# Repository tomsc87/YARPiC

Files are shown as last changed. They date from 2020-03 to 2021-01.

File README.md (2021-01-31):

[UPDATE: 31/01/2021]

Goddammit! Another update for January 2021. While playing around, trying to make a double fan top for one of my Pis, I noticed that I borked the dc_text intersection in the last update, meaning the grill went through the dc_text (and made rendering dc_text so much slower).

Here are the changes:

<ul>
<li>Fixed dc_text fan intersection.</li>
<li>Removed leftover code used for internal testing.</li>
</ul>

This really is the last update of January 2021... mainly because I probably won't notice any other bugs until tomorrow.

[UPDATE: 30/01/2021]

Okay, I lied. This really will be the final update of January 2021 (and for a while).

<ul>
<li>Added the option for double fans (some restrictions apply), which was suggested by Thingiverse user <a href="https://www.thingiverse.com/muga/" target="_blank">Muga</a>.</li>
<li>Changed the camera cutout slightly (you can't have it when you have double fans).</li>
</ul>

That's it. No more updates until my big overhaul.

[UPDATE: 28/01/2021]

This should be the final update of January 2021 (and for a while).

Here's what's changed:

<ul>
<li>Moved all hinge parts into modules.</li>
<li>Created a test part for hinge so you can dial in horizontal expansion settings without having to print out a whole case.</li>
<li>Refined hinge slightly.</li>
<li>Added cutout for camera ribbon cable. (Suggested by Thingiverse user <a href="https://www.thingiverse.com/gregkster/designs" target="_blank">Gregkster</a>.)</li>
<li>Updated .json file.</li>
</ul>

Future updates will come few and far between. I have some ideas; however, they'll take some time and will likely require a complete redesign.

[UPDATE: 25/01/2021]

Today, I bring you the long-awaited hinged cover for the microSD card slot. It's still experimental, and you may need to adjust your horizontal expansion settings in your slicer software. It is rather slap-dash at the moment, so it increases render times by between 20 and 25% compared with the "Open" option, but I will refine it over time.

Here are all the changes:

<ul>
<li>Changed sd_card options to include the hinged cover. ("Yes" is now "Open", "No" is now "Closed", and added "Cover (experimental)" for the hinged cover.)</li>
<li>Updated the .json file.</li>
<li>Minor bug fixes.</li>
</ul>

In the next update, I hope to refine the microSD card cover enough so you can print out a test of it without having to waste time and material by printing out a full case to get your horizontal expansion settings dialled in. I might also add an option for a camera ribbon cable cutout in the top of the case as well as camera mounting options; however, they're low on my priorities list right now.

[UPDATE: 21/01/2021]

Just a small update, with no new features, but tidied up the code.

Here are the changes:

<ul>
<li>Ports for different models merged together. (Using mostly inline conditionals, but some nested conditionals where needed.)</li>
<li>Moved front and side ports into separate modules. (So you don't have to render ports twice when new_io is set to "yes".)</li>
<li>Using inline conditional for building the main body of bottom() instead of nested conditional. (Had already done this for top(), but never got round to doing it for bottom().)</li>
</ul>

In all, 109 lines of code have been removed in this update.

Still working on a hinged cover for the microSD card. Might commit that to a new branch tomorrow.

[UPDATE: 13/01/2021]

It's been a crazy 9 months. Happy new year. Hope you're all doing well. Most of my time was spent doing nothing with YARPiC; however, over the last 2 months, YARPiC has gone through quite a few revisions that I've been too busy to finalize and upload (or "commit" as I think I recall it being known as on the GitHubs).

Anyway, here are the changes:

<ul>
<li>Option of a deeper side cutout to give better clearance to HDMI (because the Pi has to go in sideways with this option, I've added a cutout at the back when sd_card option is set to "no" to give clearance; if sd_card option is set to "yes", you can just insert the microSD card after installing the board) (only tested on Pi4B with corners option set to "yes"; might be some clearance problems with Pi3A and Pi3B with corners option set to "no" (I've tried to mitigate it, but, again, I haven't tested it)).</li>
<li>Tapered board screw holes when corners option set to "yes" to better guide screws.</li>
<li>(Almost) complete freedom to manipulate text; text can be moved anywhere and rotated any amount (in 0.5 degree increments); spacing between two lines of text can be increased or decreased; text can even be printed in the fan grill, but it won't cover the screw holes.</li>
<li>Added option for rail mounting from rear (SD card side) of the case for better clearance when mounting to Prusa i3 printers.</li>
<li>Option for cooling slots along the GPIO side of the case, as well as both the SD card side and GPIO side (untested).</li>
</ul>

I think that's everything that's been changed. Might have moved the USB and ethernet slightly, but nothing major. Oh, and I finally got round to sorting out the indents (that was a pain in the arse).

In the next update, I'll probably just tidy up the ports, which should get rid of between 50 and 70 lines of code. I was also working on a hinged cover for the microSD card; however, it was getting a bit too demanding, so I put that on hold; maybe that will be in the next update as well.

[UPDATE: 21/04/2020]

Small update. Here's the changes:

<ul>
<li>Removed the restriction for rail and corners together.</li>
<li>Added embedded screw hole to the rail.</li>
<li>Added new corner/rail combination to examples.</li>
<li>Changed the lip on the top of case so it no longer uses the Minkowski function (cuts about 2 seconds off the render time).</li>
</ul>

[UPDATE: 12/04/2020]

All the customizability you've come to expect from YARPiC, but now in a smaller form factor. Here's what's new:

<ul>
<li>Added support for the Raspberry Pi 1 Model A+ and 3 Model A+.</li>
<li>Lots of translates to make A+ work smoothly.</li>
<li>Added option to fully embed screws on fans and/or corners.</li>
<li>Removed most unused code.</li>
<li>Tidied up code (especially most of the misplaced indents caused by commenting out sections of code).</li>
</ul>

As always, feedback would be much appreciated.

[UPDATE: 30/03/2020]

Minor update.

<ul>
<li>Merged part translates from "touchscreen" branch because they're cleaner.</li>
<li>Merged GPIO/fan translate from mkgin's fork because it helps remove redundant code.</li>
</ul>
</ul>

[UPDATE: 12/03/2020]

Another small update.

<ul>
<li>Redesigned nut trap for corners.</li>
<li>Fixed corner impinging on front cutout for Pi4.</li>
</ul>

[UPDATE: 09/03/2020]

Just a small update. I've tweaked the edge_detection function for "dc_text" and made it default. It doubles render times for dc_text (when set to bevelled), but that comes out at 6 seconds (much better than the 38 seconds in the last update). Unfortunately, when bevel is set to "no", it comes out at 16 seconds for reasons that I don't fully understand because it's completely illogical (it's still better than 38 seconds). As a result, if your text doesn't extend beyond the edge of the case, I recommend rendering dc_text with bevel set to "yes", even if you don't have bevel enabled on the case.

[UPDATE: 08/03/2020]

Lots of changes in this update.

<ul>
<li>Bevelled side cutout (power, HDMI, audio) to make printing easier.</li>
<li>Larger micro HDMI cutouts for Pi 4.</li>
<li>Option to remove access to SD card (suggested by @<a href="https://www.thingiverse.com/mikegi/about" target="_blank">mikegi</a>).</li>
<li>Moved corner nut housing up a bit (M3*16 bolts can be used instead of M3*20), made slightly wider (so nuts fit in better), and added a hexagon (so it holds nuts in place better).</li>
<li>Added supports for corner nut housing roof (can easily be removed in post processing with side cutters or a craft knife).</li>
<li>Added a full layer above corner nut housing as support for screw hole (can easily be removed in post processing with a drill, file, or even just a screw if you're lazy (like me)). (Can be adjusted for different layer heights.)</li>
<li>New embedded screw holes on top of case with corners set to "yes". (I.e. no more need for supports.)</li>
<li>screw_hole variable now sets the screw hole size for the stand offs when corners is set to "yes". (Was overlooked before because I never print with corners any more.)</li>
<li>Dual colour text edge detection. Now the text can extend beyond the edge of the case and dc_text will conform to it. (<strike>Must be set manually because it drastically increases render times.</strike>)</li>
<li>Minor code refinements to help reduce render times.</li>
</ul>

I think that's all the changes in this update.

Again, Thingiverse isn't giving out the correct file in the main download, so go to Thing Files and download YARPiC_March_2020.zip to get the most recent version.

[ORIGINAL]

I couldn't find a Raspberry Pi case that I liked or that met my needs, so I made one myself.

My basic requirements were:
<ul>
<li>Could house an Asus Tinker Board with stock heatsink</li>
<li>Could house a 40*40*10 fan as well</li>
<li>Used nuts and bolts (since clip together cases always break)</li>
<li>Not too thin and flexible (too many cases on here have, like, 0.5mm thick surfaces, which is just too flexible)</li>
<li>Could fit my chunky Amazon Basic USBs</li>
<li>Didn't look like it was trying to be a retro console (the most important thing)</li>
</ul>

After a couple of hours in OpenSCAD and a few prototypes later, I give you YARPiC.

To properly use it, you will need:
<ul>
<li> 4 x M3*16 bolts (for the fan)</li>
<li> 4 x M3*20 bolts (for the lid)</li>
<li> 8 x M3 nuts (for the fan and lid)</li>
<li> 4 x M2.5*5 screws (for the board)</li>
<li> 1 x Raspberry Pi (1 B+, 2 B, 3 B, 3 B+) or Tinker Board (or any SBC with the same form factor)</li>
<li> 1 x 40*40*10mm fan (ideally 5V; I went for the Noctua one)</li>
</ul>

Tree supports in Cura are awesome, but they're not perfect, so you might need to tidy up the nut housing; I used a craft knife, small circular file, and a pair of tweezers to get it looking nice.

[UPDATE: 15/03/2019]

I've included a customizable OpenSCAD file, so you can customize YARPiC to your needs.

What you can now do:
<ul>
<li>Change fan size.</li>
<li>Add slot for GPIO.</li>
<li>Bevel the edges.</li>
<li>Add exhaust slots.</li>
<li>Add embedded text.</li>
<li>Add dual colour text.</li>
<li>Change wall size.</li>
<li>Render bottom, top, and text separately.</li>
</ul>

If you have any questions, complaints, or suggestions, feel free to leave a comment.

[UPDATE: 19/03/2019]

I wanted to mount this case to my printer because I wasn't happy with the case I had. As a result, I had to find a way to add a V-slot rail to it, which meant I had to get rid of the corner screws and find another way to fix the lid in place. Thus, I give you "YARPiC No Corners". This is the intermediary stage (without the V-slot rail), and a preview of things to come.

What you'll need:
<ul>
<li>4 x M3*16 bolts (for the fan)</li>
<li>4 x M3 nuts (for the fan)</li>
<li>4 x M2.5*8 screws</li>
<li>Raspberry Pi</li>
<li>40*40*10mm 5V fan</li>
</ul>

Again, you will need to slice with supports (ideally tree supports in Cura) so that the embedded screw holes don't collapse when printing.

In the coming days, I will add the alterations to the customizer so you can add text, change fan size, add V-slot rail etc.

[UPDATE: 23/03/2019]

As promised, here's the updated version of the YARPiC customizer so you can make YARPiC without the corner screw holes.

Here's what's new:
<ul>
<li>Option to remove the corner screw holes and add through-board screws for the top.</li>
<li>Add V-slot mounting rail for 3D printers that use 2020, 2040, 4040 extrusion. (NOTE: V-slot cannot be used with corners.)</li>
<li>Up to two lines of text.</li>
</ul>

Bug fixes:
<ul>
<li>Fixed bevelled edge with GPIO set to "yes".</li>
</ul>

As always, I hope you enjoy, and look forward to seeing your creations. If you have any questions, suggestions, or complaints, leave a comment. 
[UPDATE: 04/04/2019]

Did someone say "VESA mounts"? Okay, no one said "VESA mounts", but I decided to add them anyway.

Updates:
<ul>
<li>VESA mounts.</li>
</ul>

As always, if you have any complaints, comments, or suggestions, leave them in the comments.

[UPDATE: 02/04/2019]

Bug fix:
<ul>
<li>Increased the size of screw holes from 2.6mm to 3mm to reduce stress on (and subsequent breakage of) the top when "corners" is set to "No".</li>
<li>Fixed screw towers going through text on lid.</li>
</ul>

[UPDATE: 25/06/2019]

Added support for the new Raspberry Pi 4 Model B. This is untested. While I do have my Pi 4, all my printers are out of action at the moment. As a result, feedback would be greatly appreciated.

[UPDATE: 22/08/2019]

My main printer is working again, so I've been able to work on this again.

Change log:
<ul>
<li>Modified fan grill to decrease render time (by up to ~43%) and increase airflow (~6.5% better cooling)</li>
<li>Smaller power port when Pi4 is set to "No"</li>
<li>Deeper screw holes on the bottom </li>
<li>Modified top mounts to make them stronger</li>
<li>Added screw hole test</li>
</ul>

Things I still have to do:
<ul>
<li><strike>Rewrite the entirety of the top of the case because the code is a mess and drastically increases render times.</strike></li>
</ul>

[UPDATE: 25/08/2019]

I notices there was a problem with the standoffs breaking (caused by the deeper screw holes bug fix in the last update), so this is a quick bug fix for that.

Changes:
<ul>
<li>Changed diameter of standoffs from 6mm to 8mm to stop breakage. (Untested, but should work)</li>
</ul>

[UPDATE: 06/09/2019]

Right, I've done a massive overhaul. Here are the changes:

<ul>
<li>Removed the reliance on the third-party bevel library for the bevelled edge option</li>
<li>Fewer, larger cooling slots on the back to increase airflow slightly</li>
<li>Embedded screw holes that no longer need supports</li>
<li>Added cutout for easier insertion and removal of Pi4</li>
</ul>

I think that's all the changes. As always, feedback would be much appreciated.

[UPDATE: 18/09/2019]

I finally installed OpenSCAD 2019.05 and discovered the amazing Customizer in there, so I've made yarpic_customizer.scad compatible with that. I think it makes my code more of a mess, but it makes it easier to use with the built-in Customizer. And, with it, I've included a .json file with some pre-configured YARPiCs (including the one I use to test render times).

Speaking of render times, I've also tidied up the code in the maths/yarpic_model.scad file (removing redundant code that got added over time), resulting in ~38% faster render times (compared with the first Raspberry Pi 4 revision).

Also, I noticed a bug where the fan mesh stuck out the side of the case when "gpio" and "fan" were set to "yes", so I made the mesh smaller. Because of this, I didn't include an option for 50mm fan in the Customizer (although, you can add it manually), so the smaller mesh shouldn't be a problem (not that you can fit a 50mm fan in the case with "gpio" set to "yes" anyway (I'm not even sure a 50mm fan will fit in the case without "gpio" set to "yes" because I haven't tried it)).

Finally, I've made it so you cannot render the "screwtest" or "dc_text" with the case itself. Obviously, rendering "dc_text" with the case would defeat the purpose of having text (because it would fill in the text in the .stl). And the "screwtest" only takes 15 minutes to print and should be printed (and the "screw_hole" variable set correctly) before you print the case anyway.

Well, I think that's all the changes in this (hopefully final) revision.

If you notice any bugs, let me know in the comments section.

[UPDATE: 13/02/2020]

Just a small update with two changes:

<ul>
<li>Changed the V/T-slot. It now requires two M3 T-nuts and two M3x8 bolts. This makes it a lot stronger.</li>
<li>Reduced the default fragment number ($fn) from 50 to 24. It doesn't reduce detail too much, but halves the render time, so it's a worthy trade off. Of course, you can still set it whatever you like in the customizer.</li>
</ul>

Thingiverse is still giving out the 18th September 2019 update when you click "download all files", so, for the time being, go over to the "thing files" tab and download the "yarpic_customizer_2020.zip" file from there.

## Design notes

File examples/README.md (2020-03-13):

<h1><u>YARPiC Examples</u></h1>

Feel free to upload your customized YARPiC .stl files, and leave a little note about what you're using YARPiC for (e.g. Pi-Hole, daily driver, home automation, etc).

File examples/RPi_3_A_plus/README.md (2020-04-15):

<h1><u>Raspberry Pi 3 Model A +</u></h1>

I had the random urge to add support for the 1 A+ and 3 A+ models.

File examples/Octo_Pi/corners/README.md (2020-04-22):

<h1><u>OctoPi</u></h1>

With the new rail design, I figured I could allow corners and rail together. This was the test print of that, and it works well.

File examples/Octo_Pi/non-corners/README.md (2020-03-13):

<h1><u>OctoPi</u></h1>

To communicate with my printers, I use OctoPi (OctoPrint) on a Raspberry Pi 3 Model B. This is attached to my main printer (Geeetech A10M) with this YARPiC. It's the reason I got rid of corners for a while (see the main README.md for the full story behind that)..

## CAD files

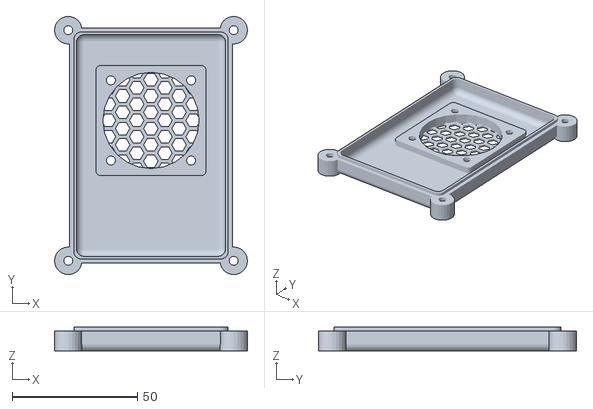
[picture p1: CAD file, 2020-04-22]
examples/Octo_Pi/corners/OctoPi_corners_top.stl
77.0 x 103.0 x 9.47

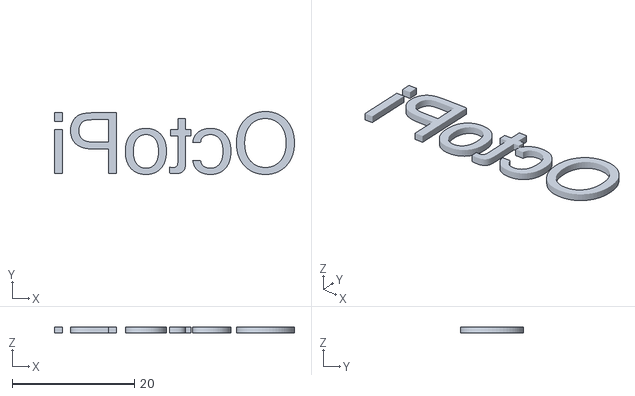
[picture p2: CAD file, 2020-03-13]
examples/Octo_Pi/non-corners/OctoPi_text.stl
39.3 x 10.3 x 1.00

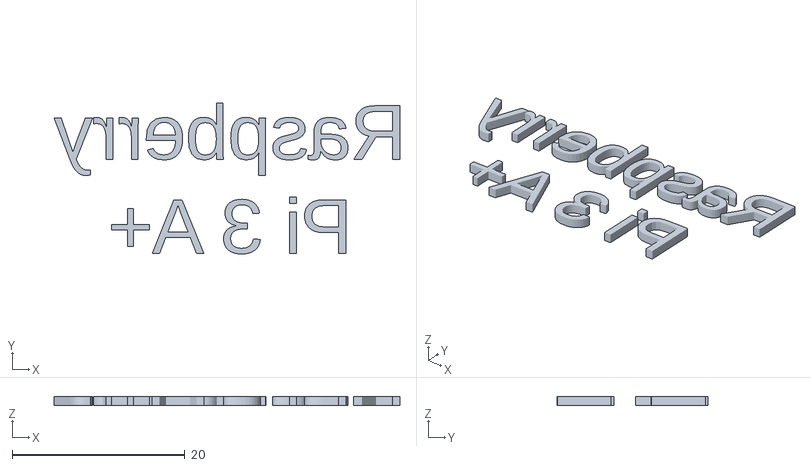
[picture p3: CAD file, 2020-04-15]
examples/RPi_3_A_plus/yarpic_text.stl
40.0 x 17.5 x 0.999

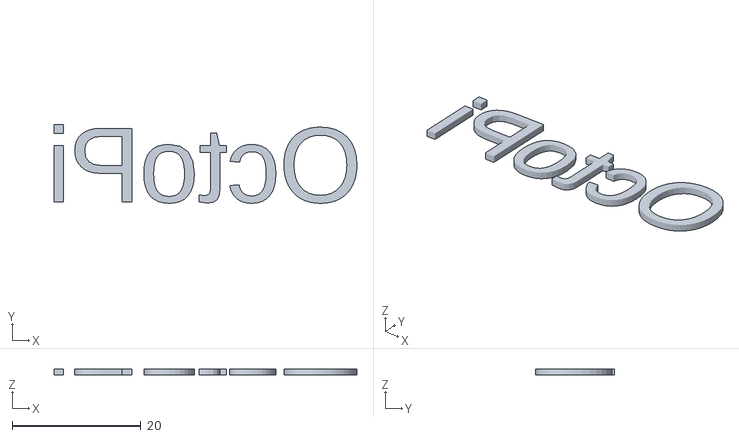
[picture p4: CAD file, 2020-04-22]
examples/Octo_Pi/corners/OctoPi_corners_top_text.stl
47.0 x 12.2 x 0.999

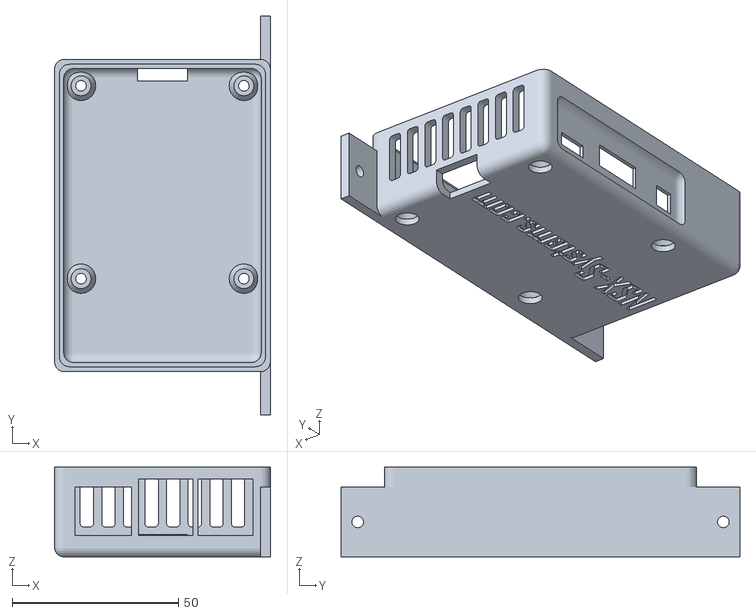
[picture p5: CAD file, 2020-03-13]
examples/Octo_Pi/non-corners/OctoPi_bottom.stl
65.0 x 120.0 x 27.0

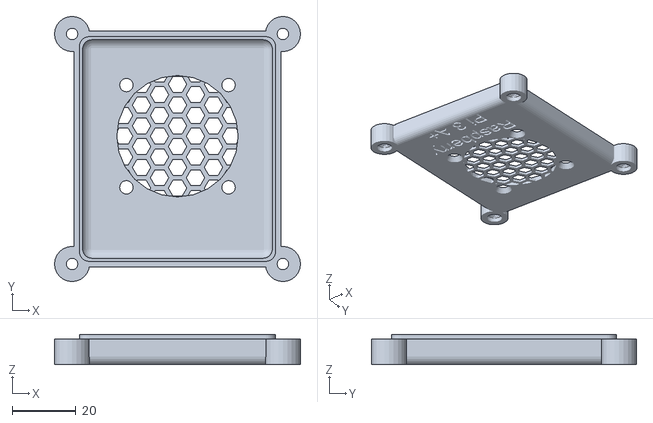
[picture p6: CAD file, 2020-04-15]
examples/RPi_3_A_plus/yarpic_top.stl
77.0 x 83.0 x 9.47

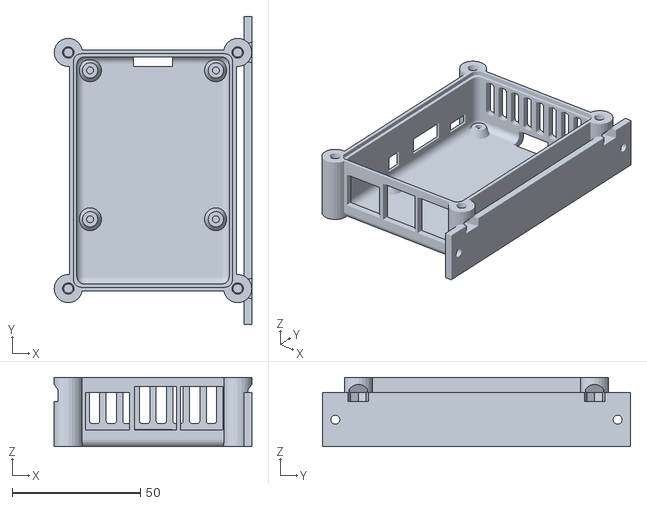
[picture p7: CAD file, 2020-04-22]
examples/Octo_Pi/corners/OctoPi_corners_bottom.stl
77.0 x 120.0 x 27.0

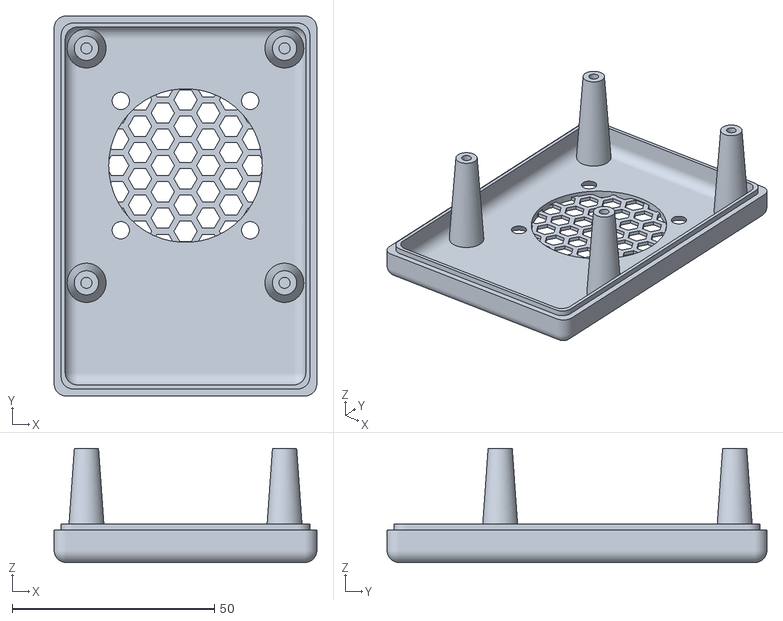
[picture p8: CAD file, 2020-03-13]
examples/Octo_Pi/non-corners/OctoPi_top.stl
65.0 x 94.0 x 28.2

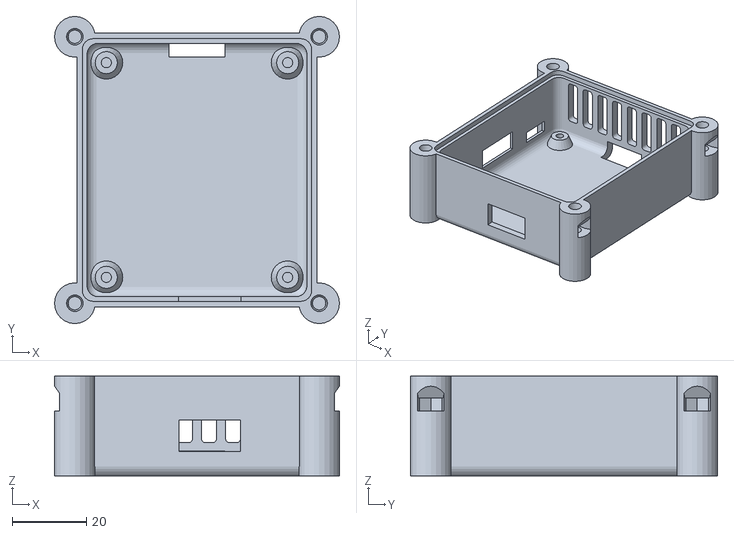
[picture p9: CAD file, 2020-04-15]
examples/RPi_3_A_plus/yarpic_bottom.stl
77.0 x 83.0 x 27.0

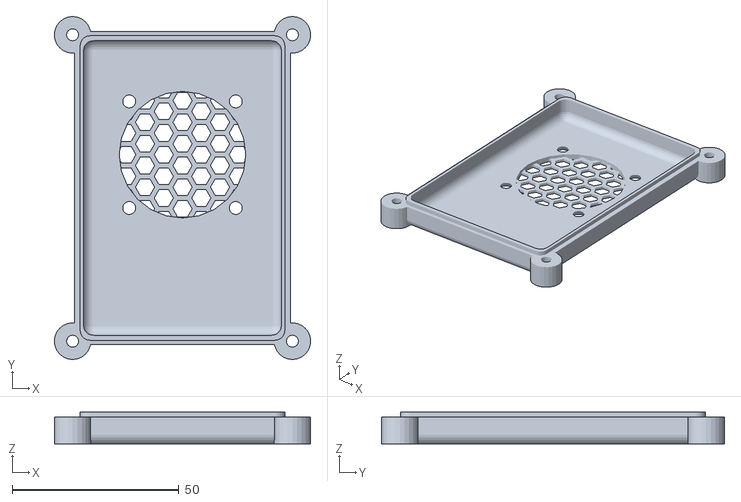
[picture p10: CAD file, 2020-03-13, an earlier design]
examples/Tinker_test/yarpic_top.stl
77.0 x 103.0 x 9.47

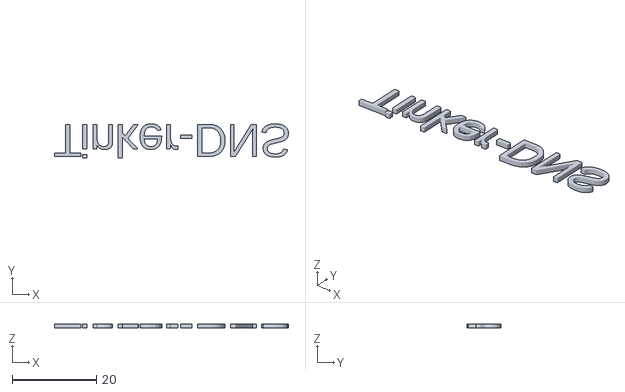
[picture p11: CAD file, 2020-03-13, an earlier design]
examples/Tinker_test/yarpic_text.stl
55.7 x 8.19 x 0.999

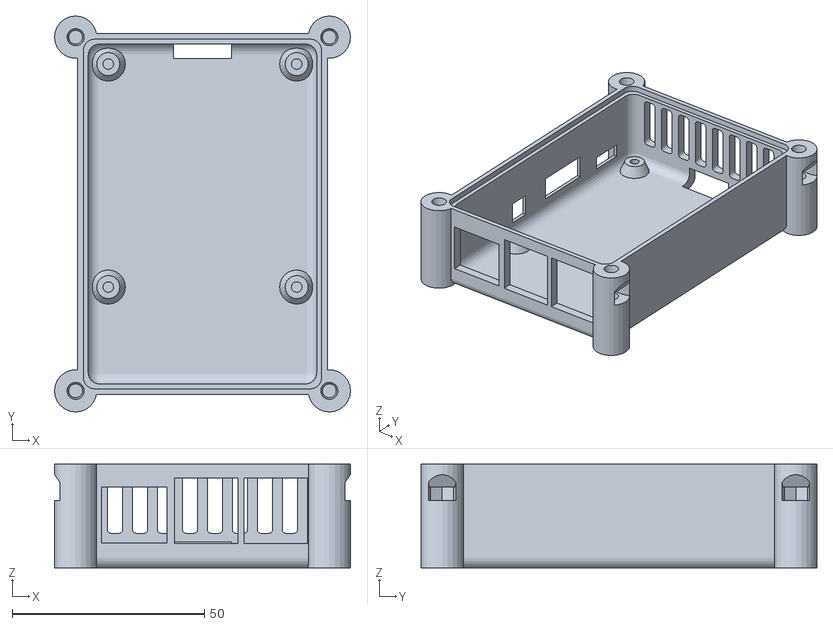
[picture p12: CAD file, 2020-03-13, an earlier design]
examples/Tinker_test/yarpic_bottom.stl
77.0 x 103.0 x 27.0

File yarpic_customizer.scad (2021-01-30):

// Hello, you lovely people. I added some more features to my Yet Another Raspberry Pi Case (YARPiC), and decided to release a customizable source code for you.

// To make it as simple as possible, I've split it into two parts: 1) a customizer (this document), and 2) another file that does all the hard work (maths/yarpic_model.scad). If I've done my job correctly, you shouldn't need to touch the latter (and see how much of a mess my coding is).

// Anyway, I hope you find this easy to use and post your makes to Thingiverse. If you have any comments, complaints, or suggestions, feel free to leave a comment (here: https://www.thingiverse.com/thing:3464513, or here: http://github.com/tomsc87/YARPiC).

include <maths/yarpic_model.scad>

/*[Main]*/

// Moves the ports around for different models.
model="pi3b"; //[pi3b:Raspberry Pi 1 B+/2 B/3 B/3 B+/Tinker Board,pi4:Raspberry Pi 4 B,pi3a:Raspberry Pi 1A+/3A+]

// Render both top and bottom, or just top or bottom.
part="both"; // [both:Both,bottom:Bottom,top:Top]

// For bevelled top and bottom edges. This seriously reduces performance, so change this last if you want bevelled edges.
bevel="no"; //[no:No,yes:Yes]

// This re-adds the corners from my original design and removes the through-board screw holes to hold the top in place. This cannot be used with the V-slot mounting rail.
corners="no"; //[no:No,yes:Yes]

// If using corners, set the layer height you plan to print at so a single layer gets printed above the nut housing as a base for the screw holes. You can use a drill or small circular file to remove it in post processing. If not using corners, this doesn't need to be set.
layer_height=0.2;

// Increase to add smoothness (slow render); decrease to reduce smoothness (fast render). Default is "24".
$fn=24;

/*[Bottom]*/

// Add cooling slots on the rear (microSD side) wall.
cooling_slots="no"; //[no:None,back:Back,side:Side,both:Both]

// Adds a 75*75 and 100*100 VESA mount to the bottom of the case. The 100*100 works with corners, but the 75*75 might be a bit close (I haven't actually tested it yet). Also, cannot be used with rail.
vesa="no"; //[no:No,yes:Yes]

// Adds mounting holes for 2020 aluminium (aluminum) extrusion V-slot so you can mount the case to a 3D printer that uses V-slots such as the Creality Ender 3, Geeetech A10(M)/A20(M)/A30(M), or Original Prusa i3 MK3(S).
rail="no"; //[no:None,side:Side,back:Back]

// Thingiverse user mikegi wanted the option to have the SD card covered, so here it is.
sd_card="open"; //[open:Open,closed:Closed,cover:"Covered (experimental)"]

// Moves the side I/O cutout in for better HDMI clearance. Also adds spacing at back if you have sd_card set to "closed".
new_io="no"; //[no:No,yes:Yes]

/*[Top]*/

// Adds access to GPIO header through lid. This will also offset the fan slightly (if fan is enabled).
gpio="no"; //[no:No,yes:Yes]

// Adds fan hole (or two) on lid. The Double option doesn't work on 40mm fans (yet) or fans larger than 25mm with the "Raspberry Pi 1A+/3A+" model option, and will just default to Single.
fan="no"; //[no:No,single:Single,double:Double]

// Change fan size. It should work for any size fan (assuming it fits in the case); however, I've only tried it with the sizes that are listed. Input should be in millimetres between "25" and "40".
fan_size=40; //[25,30,40]

// This option allows you to fully embed the fan and/or corner screws for a cleaner look. (Might not work with 25mm fans.)
full_embed="no"; //[yes:Yes,no:No]
// Thingiverse user Gregkster suggested a cutout for a camera ribbon cable, so that's what I've done. Unfortunately, I have no camera mounting options, yet; however, I might do that in a future update.
camera="no"; //[yes:Yes,no:No]

/*[Text options]*/

// Add text. Pretty obvious, right?
add_text="no"; //[no:No,yes:Yes]

// Whatever you put in the quotation marks will appear on the top of the case.
line1="YourTextHere1";

// Same as above. However, you can leave this blank for just a single line.
line2="YourTextHere2"; 

// Check "Help > Font List" to see all available fonts (try "Chiller"; it's my favourite). (I might add a dropdown font list in future revisions.)
font="";

// This is pretty obvious.
text_size=6.5; //[5:0.5:13]

// Rotate text allows you to have more than just 0 and 180 degrees on the text.
rotate_=0; // [-180:0.5:180]

// This moves the text up (positive) and down (negative). Movement is absolute (i.e. relative to the case, not the text itself), so rotation will have no impact on the location. Another thing to note is that the text can go through the fan grill, but not the fan holes.
move_y=0; // [-10:0.5:70]

// This moves the text left (positive) and right (negative). (Yes, the slider is inverted, but there's not a lot I can do about that.)
move_x=0; // [-10:0.5:10]

// This adjusts the spacing between the two lines of text.
spacing=0; //[-10:0.5:10]

// This adds a dual colour option for text. Obviously, you have to render this separately from everything else.
dc_text="no"; //[no:No,yes:Yes]

/*[Test]*/

// If you want to use the "Covered" option for sd_card, it's recommended that you print a sample of the hinge so you can dial in your slicer's horizontal expansion settings. It should take up to 20 minutes to print, and it's better than spending 7 hours on a print that's wasted because the cover won't open or is too loose.
hingetest="no"; //[no:No,yes:Yes]

// After changing hotend and nozzle on my printer, I was having problems with the screw holes for the top not being tight enough to grip the screws. Instead of printing out a new top every time, I made a test to get the right size.
// Print this out and then change the variable "screw_hole" if your screws are too tight (increase the variable) or too loose (decrease the variable) until the screws fit snugly.
screwtest="no"; //[no:No,yes:Yes]
screw_hole=2.45;

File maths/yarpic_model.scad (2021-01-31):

// Hello, you lovely people. I added some more features to my Yet Another Raspberry Pi Case (YARPiC), and decided to release a customizable source code for you. 

// To make it as simple as possible, I've split it into two parts: 1) a customizer (../yarpic_customizer.scad), and 2) another file that does all the hard work (this file). If I've done my job correctly, you shouldn't need to touch the latter (and see how much of a mess my coding is).

// Anyway, I hope you find this easy to use and post your makes to Thingiverse. If you have any comments, complaints, or suggestions, feel free to leave a comment (here: https://www.thingiverse.com/thing:3464513, or here: https://github.com/tomsc87/YARPiC ).

// DON'T TOUCH!! Important maths stuff. DON'T TOUCH!!

if((rail=="side"||rail=="back")&&(vesa=="yes")){
    translate([0,sd_card=="cover" ? 10:0,0]) linear_extrude(2) text("Turn off either rail or vesa.", halign="center", valign="center");
}
else{}

if(rail=="back"&&sd_card=="cover"){
	translate([0,vesa=="yes" ? -10:0,0]) linear_extrude(2) text("Turn off either back rail or SD cover.", halign="center", valign="center");
}
else{}

if(part=="bottom"){
	if((rail!="no"&&vesa=="yes")||(dc_text=="yes")||(screwtest=="yes")||(hingetest=="yes")||(rail=="back"&&sd_card=="cover")){}
    else{
        translate([0,model=="pi3a" ? -10:0,0]) bottom();
    }
}
else {}

if(part=="top"){
    if((rail=="side"||rail=="back")&&vesa=="yes"||(dc_text=="yes")||(screwtest=="yes")||(hingetest=="yes")){}
    else{
        translate([0,model=="pi3a" ? -10:0,0]) top();
    }
}
else {}

if(part=="both"){
    if((rail=="side"||rail=="back")&&vesa=="yes"||(dc_text=="yes")||(screwtest=="yes")||(hingetest=="yes")||(rail=="back"&&sd_card=="cover")){}
    else{
        translate([-50,model=="pi3a" ? -10:0,0]) top();
        translate([50,model=="pi3a" ? -10:0,0]) bottom();
        if(vesa=="yes"){
			translate([50,model=="pi3a"&&corners=="yes" ? -10:0,0]) vesa();
        }
        else{}
    }
}
else{}

if(dc_text=="yes"){
    if(screwtest=="yes"||hingetest=="yes"){}
    else{
        if(part=="both"){
            translate([-50,model=="pi3a" ? -10:0,0]) dc_text();
        }
        else if(part=="top"){
            translate([0,model=="pi3a" ? -10:0,0]) dc_text();
        }
        else{}
    }
}
else {}

if((vesa=="yes")&&(part=="bottom")){
    if((rail=="side"||rail=="back")&&(corners=="yes"||vesa=="yes")||(dc_text=="yes")||(screwtest=="yes")||(hingetest=="yes")){}
    else{
        translate([0,model=="pi3a"&&corners=="yes" ? -10:0,0]) vesa();
    }
}
else {}

if(screwtest=="yes"){
	if(hingetest!="yes"){
		screwtest();
	}
	else{}
}
else {}

if(hingetest=="yes"){
	if(screwtest!="yes"){
		hinge();
	}
	else{}
}
else{}

if(screwtest=="yes"&&hingetest=="yes"){
	translate([0,0,0]) linear_extrude(2) text("Turn off either screwtest or hingetest.", halign="center", valign="center");
	}
else{}

module bottom(){
    difference(){
        union(){
            difference(){
                union(){
                    difference(){
                        union(){
                            // Case
                            if(bevel=="yes"){
                                translate([0,model=="pi3a" ? 10:0,2.975]){
                                    minkowski(){
                                        linear_extrude(27)  square([59,model=="pi3a" ? 68:88], center=true);
                                        sphere(3);
                                    }
                                }
                            }
                            else{
                                translate([0,model=="pi3a" ? 10:0,0]) linear_extrude(27) offset(3) offset(-3) square([65,model=="pi3a" ? 74:94], center=true);
                            }
                            // V-slot
                            if(rail=="side"){
                                difference(){
                                    union(){
                                        translate([corners=="yes" ? 37:31,model=="pi3a" ? 10:0,0]) linear_extrude(21) square([3,model=="pi3a" ? 100:120], center=true);
                                    }
                                    for (y=model=="pi3a" ? 45*[1,-1]:55*[1,-1]){
                                        translate([corners=="yes" ? 39.5:33.5,model=="pi3a" ? 10+y:y,10.5]) rotate([0,-90,0]) linear_extrude(10) circle(d=3.6);
                                        translate([corners=="yes" ? 37:31,model=="pi3a" ? 10+y:y,10.5]) rotate([0,-90,0]) linear_extrude(10) circle(d=6);
                                    }
                                }
                            }
                            else if(rail=="back"){
                                difference(){
                                    union(){
                                        translate([0,corners=="yes" ? 50:45.5,0]) linear_extrude(corners=="yes" ? 17.5:21) square([95,3], center=true);
                                    }
                                    for(X=42.5*[1,-1]){
                                        translate([X,corners=="yes" ? 52:47,10.5]) rotate([90,0,0]) linear_extrude(10) circle(d=3.6);
                                        translate([X,corners=="yes" ? 50:45.5,10.5]) rotate([90,0,0]) linear_extrude(10) circle(d=6);
                                    }
                                }
                            }
							else{}
                        }
                        // Rear holes for airflow
                        if(cooling_slots=="back"||cooling_slots=="both"){
                            rotate([90,0,0]) translate([0,14,-48]){
                                linear_extrude(6) for(X=[-22.75:6.5:22.75], Y=2.5) translate([X,Y,-1]) offset(1) offset(-1) square([4,15], center=true); // As awful as this is with the rotate, it's a LOT better than the alternative (minkowski).
                            }
                        }
                        if(cooling_slots=="side"||cooling_slots=="both"){
                            translate([29,model=="pi3a" ? 10:0,17]) rotate([0,90,0]){
                                linear_extrude(6) for(Y=model=="pi3a" ? [-22.75:6.5:22.75]:[-35.75:6.5:35.75]) translate([0,Y,0]) offset(1) offset(-1) square([15,4], center=true);
                            }
                        }
                        else{}
						if(new_io=="no"){
							side_io();
						}
						else{}
						front_io();
						translate([new_io=="yes" ? -30:-35.75,11,6]){
							minkowski(){
								linear_extrude(model=="pi4" ? 8.5:12) square([4,55], center=true);
								sphere(3);
							}
						}
                    }
                    if(corners=="yes"){
                        // Corners
                        translate([0,model=="pi3a" ? 10:0,0]) linear_extrude(27) for(X=33*[-1,1], Y=model=="pi3a" ? 36*[-1,1]:46*[-1,1]) translate([X,Y,-1])  circle(d=11);
                    }
                    else{}
                }
				if(model=="pi4"||model=="pi3a"){
					// Front cutout
					translate([model=="pi3a" ? 3.45:-0.5,model=="pi3a" ? -24:-44,6.4]) linear_extrude(20) square([model=="pi3a" ? 17:55,3], center=true);
				}
				else{}
				// Hollow out for lid
				translate([0,model=="pi3a" ? 10:0,25.25]) linear_extrude(10) offset(3) offset(-3) square([62,model=="pi3a" ? 71:91], center=true);
				if(bevel=="yes"){
					// Cut off top
					translate([0,model=="pi3a" ? 10:0,27]) linear_extrude(9) square([79,model=="pi3a" ? 98:118], center=true);
					// Hollow out
					minkowski(){
						translate([0,model=="pi3a" ? 10:0,5]) linear_extrude(30) square([53.5,model=="pi3a" ? 62.5:82.5], center=true);
						sphere(3);
					}
				}
				else{
					translate([0,model=="pi3a" ? 10:0,2]) linear_extrude(30) offset(3) offset(-3) square([59.5,model=="pi3a" ? 68.5:88.5], center=true);
				}
                if(corners=="yes"){ // I could add all this to the nut_trap() module, but it adds about 10 seconds to the render time.
                    translate([0,model=="pi3a" ? 10:0,0]){
                        for(X=33*[-1,1], Y=model=="pi3a" ? 36*[-1,1]:46*[-1,1]){
                            translate([X,Y,23.5+(layer_height*4)]) cylinder(d1=3.6,d2=3.6+1.6,h=5);
                            translate([X,Y,15]) cylinder(d1=3.6,d2=3.6+1.6,h=5);
                            // Screw holes
                            translate([X,Y,15-1]) linear_extrude(20) circle(d=3.6);
                            // New nut trap
                            translate([33,Y,17.5]) nut_trap();
                            translate([-33,Y,17.5]) rotate([0,0,180]) nut_trap();
                        }
                    }
                }
                else{}
            }
            // Stand offs
            translate([0,10,1.9]){
                for(X=24.5*[-1,1], Y=29*[-1,1]){
                    translate([X,Y,0]) cylinder(d1=9, d2=6, h=3.4);
                }
            }
        }
        if(corners=="yes"){
            // Screw holes
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

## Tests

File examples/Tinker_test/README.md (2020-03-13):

<h1><u>Tinker-DNS</u></h1>

I'm using an Asus Tinker Board with Armbian Lite as a Pi-Hole. It's got a 40mm Noctua 5V fan, and it's actually the reason I started this project just over a year ago.

The .stl files were for the test print of the new corners design, and they've come out better than I was expecting.

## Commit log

2020-03-10 New March 2020 update. Refinement to edge_detection, which is now default.
    [yarpic_customizer.scad, yarpic_model.scad]
2020-03-10 New corner screw hole supports.
    [yarpic_model.scad]
2020-03-11 This is a test model of just the corners to hone in the values for the new supports.
    [corner_test.scad]
2020-03-11 Removed the need for supports on outer shell.
    [corner_test.scad]
2020-03-12 Completely redesigned nut trap.
    [corner_test.scad, cutout.scad]
2020-03-12 Completely redesigned nut trap and adjusted M3 screw hole values.
    [yarpic_model.scad]
2020-03-13 Added some examples.
    [yarpic_bottom.stl, yarpic_text.stl, yarpic_top.stl]
2020-03-30 Several translate mods.
    [yarpic_model.scad]
2020-04-06 Slight tidying up of code mess (it's still a mess) and fixed DC_text translate with part set to 'both'.
    [yarpic_model.scad]
2020-04-06 Finished tidying up of code mess.
    [yarpic_model.scad]
2020-04-07 Update yarpic_model.scad
    Corrected value for lip on top part of case.
    [yarpic_model.scad]
2020-04-09 New branch for April 2020 updates
    [yarpic_customizer.scad, yarpic_model.scad]
2020-04-09 Fixed manifold error on VESA mount.
    [yarpic_customizer.scad, yarpic_model.scad]
2020-04-12 Added support for RPi 1A+ and 3A+
    [yarpic_customizer.scad, yarpic_model.scad]
2020-04-12 Raspberry P 3 A+ example
    [yarpic_bottom.stl, yarpic_text.stl, yarpic_top.stl]
2020-04-12 Changed VESA mounth for 3A+
    [yarpic_customizer.scad, yarpic_model.scad]
2020-04-13 Fixed USB port location on Model A+.
    [yarpic_bottom.stl, yarpic_model.scad, yarpic_text.stl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]
2020-04-14 Added fully embeded screw option to fan screws.
    [yarpic_customizer.scad, yarpic_model.scad]
2020-04-15 Tweaked 25 and 30mm fan properties to help with full_embed option.
    [yarpic_model.scad]
2020-04-22 Added support for rail with corners.
    [OctoPi_bottom.stl, OctoPi_corners_bottom.stl, OctoPi_corners_top.stl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]
2021-01-13 January 2021 update
    [yarpic_customizer.scad, yarpic_model.scad]
2021-01-21 io refinement
    [yarpic_model.scad]
2021-01-25 Added hinged cover for microSD card cutout
    [yarpic_customizer.scad, yarpic_model.scad]
2021-01-25 Update of descriptionsin yarpic_customizer.scad
    [yarpic_customizer.scad]
2021-01-28 Added test print for microSD card cover hinge, and cutout for camera ribbon cable
    [yarpic_customizer.scad, yarpic_model.scad]
2021-01-30 Added option for double fans
    [yarpic_customizer.scad, yarpic_model.scad]
2021-01-31 Fixed bug with dc_text
    [yarpic_model.scad]
